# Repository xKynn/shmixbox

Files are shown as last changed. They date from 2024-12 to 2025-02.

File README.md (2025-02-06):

# shmixbox
Leverless keyboard style controller based on Open_Core0 WASD

## Attribution

Based on the Open_Core0 WASD board from the GP2040-CE project located at https://github.com/OpenStickCommunity/Hardware/tree/main/Boards/GP2040-CE%20Official%20Controllers/Open_Core0%20WASD

Copyright 2023 [TheTrain](https://github.com/TheTrainGoes)

[Licensed under CC BY 4.0](https://creativecommons.org/licenses/by/4.0/)

Changes from the original design:
  - Modified layout:
      - Wider spacing between D-pad and 8-button clusters.
      - Two Spacebar-like 2.5 - 3U keys to be accessible with thumbs.
      - A Shift-like 2-2.5U key under D-pad.
  - Modified GP2040-CE fork with the ability to address the Case LEDs and display the shmixbox layout on the OLED screen.
  - Street fighter inspired silkscreen art with case window. (Original Open_Core0 WASD art and window was removed)

Planned Changes:
  - Adjust switch spacing to comfortably fit MX-style caps in combination with Choc V2 switches.
  - Experimental Bridging of both thumb keys with one big spacebar keycap.
  - Replace 3U (?) stabilizer footprints and replace with 2.5U or find a combination that supports the bridging goal above.
  - Art cutout and acrylic plate files.

## Ordering and Assembling

With substituting the additional instructions below where applicable, the same instructions from Open_Core0 WASD can be followed from [here](https://github.com/OpenStickCommunity/Hardware/tree/main/Boards/GP2040-CE%20Official%20Controllers/Open_Core0%20WASD) (Make sure to use the hardware files from this repo)

### Additional Instructions
  - 16x Choc V1 or V2 switches (V1 recommended before the switch footprint spacing is adjusted).
  - 16x V1 or V2 keycaps.
  - 1x 2U Keycaps.
  - 2x 2-2.5U Keycaps.
  - Build or grab a prebuilt release of the firmware from [GP2040-CE-shmixbox](https://github.com/xKynn/GP2040-CE-shmixbox) instead of the Open_Core0 WASD firmware.

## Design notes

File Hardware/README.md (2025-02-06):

### JLCPCB Order Instructions

PCB:\
Base Material = FR-4\
Layers = 2\
Product Type = Industrial/Consumer electronics\
Different Design = 1\
PCB Thickness = 1.6\
PCB Color = Black\
Silkscreen = White\
Surface Finish = HASL(with lead)\
Outer Copper Weight = 1oz\
Via Covering = Tented\
Board Outline Tolerance = +/- 0.2mm (Regular)\
Confirm Production file = Yes\
Remove Order Number = Specify\
Flying Probe Test = Fully Test\
Gold Fingers = No\
Castellated Holes = No\
No advanced options\
\
Assembly:\
PCBA Type = Economic\
Assembly Side = Top Side\
Tooling holes = Added by Customer\
Confirm Parts Placement = Yes

------------------------------------------------------

Bottom Plate:\
Base Material = Aluminum\
Layers = 1\
Product Type = Industrial/Consumer electronics\
Different Design = 1\
PCB Thickness = 1.6\
PCB Color = Black\
Surface Finish = HASL(with lead)\
Outer Copper Weight = 1oz\
Via Covering = Tented\
Board Outline Tolerance = +/- 0.2mm (Regular)\
Confirm Production file = Yes\
Remove Order Number = Yes\
Flying Probe Test = Fully Test\
Gold Fingers = No\
Castellated Holes = No\
No advanced options

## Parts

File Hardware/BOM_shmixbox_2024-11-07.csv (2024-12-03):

ID | Name | Designator | Footprint | Quantity | Manufacturer Part | Manufacturer | Supplier | Supplier Part | Price | JLCPCB Part Class | Value
1 | C0402_NEW | C105,C98,C99,C100,C101,C102,C103,C104,C97,C93,C85,C33,C82,C83,C84,C80,C57,C58,C59,C60 | C0402_NEW | 20 | CL05B104KO5NNNC | SAMSUNG(三星) | LCSC | C1525 | 0.001 | Basic Part
2 | LED-SMD_4P-L2.0-W2.0-BR | U119,U112,U113,U114,U115,U116,U117,U118,U111,U96,U98,U99,U97,U100,U108,U86,U57,U58,U59,U60 | LED-SMD_4P-L2.0-W2.0-BR | 20 | SK6812-EC20 | 欧思科光电 | LCSC | C2909058 | 0.103 | Extended Part
3 | SW-TH_SK13D07VG4 | SW11,SW12 | SW-TH_SK13D07VG4 | 2 | SK13D07VG4 | SHOU HAN(首韩) | LCSC | C2681581 | 0.023 | Extended Part
4 | SW-TH_SK12D07VG4 | SW13 | SW-TH_SK12D07VG4 | 1 | SK12D07VG4 | SHOU HAN | LCSC | C393937 | 0.022 | Extended Part
5 | LED-SMD_4P-L4.0-W1.6-L | U84,U83,U82,U81,U80,U79,U78,U77,U76,U75,U109,U110,U95,U94,U93,U92,U91,U90,U89,U88 | LED-SMD_4P-L4.0-W1.6-L | 20 | SK6812SIDE-A-RVS | 欧思科光电 | LCSC | C2890037 | 0.088 | Extended Part
6 | F0805 | F1 | F0805 | 1 | MF-PSMF050X-2 | BOURNS | LCSC | C116170 | 0.034 | Extended Part
7 | R0603 | R35,R34 | R0603 | 2 | 0603WAF220JT5E | UNI-ROYAL(厚声) | LCSC | C23345 | 0.001 | Basic Part | 22Ω
8 | USB-A-TH_JTJ-USB-AF-13 | U7 | USB-A-TH_JTJ-USB-AF-13 | 1 | 905-261A1011D10100 | 精拓金 | LCSC | C42614 | 0.037
9 | SW-TH_4P-L6.0-W6.0-P4.50-LS6.5 | SW1,SW2,SW3,SW4,SW9 | SW-TH_4P-L6.0-W6.0-P4.50-LS6.5 | 5 | TS-1095-A11B3-D1 | Yuandi | LCSC | C493055 | 0.038 | Extended Part
10 | KEY-SMD_4P-L3.5-W3.0-P1.50-LS4.6 | SW8,SW7 | KEY-SMD_4P-L3.5-W3.0-P1.50-LS4.6 | 2 | TD-1182SA-2.0H-250 | DEALON(德艺隆) | LCSC | C2905178 | 0.039 | Extended Part
11 | SN74LV1T34DBVR | U87 | SOT-23-5_L2.9-W1.6-P0.95-LS2.8-BR | 1 | SN74LV1T34DBVR | TI(德州仪器) | LCSC | C100024 | 0.189 | Extended Part
12 | 10kΩ | R33,R29,R23 | R0402 | 3 | 0402WGF1002TCE | UNI-ROYAL(厚声) | LCSC | C25744 | 0.001 | Basic Part
13 | 100nF | C81,C18 | C0402 | 2 | CL05B104KO5NNNC | SAMSUNG(三星) | LCSC | C1525 | 0.001 | Basic Part
14 | AMS1117-3.3 | U85 | SOT-223-3_L6.5-W3.4-P2.30-LS7.0-BR | 1 | AMS1117-3.3 | AMS | LCSC | C6186 | 0.136 | Basic Part
15 | 0Ω | R30 | R0603 | 1 | 0603WAF0000T5E | UNI-ROYAL(厚声) | LCSC | C21189 | 0.001 | Basic Part
16 | 5.1kΩ | R31,R32 | R0402 | 2 | 0402WGF5101TCE | UNI-ROYAL(厚声) | LCSC | C25905 | 0.001 | Basic Part
17 | SMF05CT1G | D2 | SOT-363_L2.0-W1.3-P0.65-LS2.1-TL | 1 | SMF05CT1G | onsemi(安森美) | LCSC | C15879 | 0.146 | Basic Part
18 | 10uF | C78,C79 | C1206 | 2 | CL31A106KBHNNNE | SAMSUNG(三星) | LCSC | C13585 | 0.032 | Basic Part
19 | TYPE-C 16PIN 2MD(073) | USB2 | USB-C-SMD_TYPE-C-6PIN-2MD-073 | 1 | TYPE-C 16PIN 2MD(073) | SHOU HAN(首韩) | LCSC | C2765186 | 0.054 | Extended Part
20 | 33pF | C63,C64 | C0402 | 2 | 0402CG330J500NT | FH(风华) | LCSC | C1562 | 0.001 | Basic Part
21 | 1uF | C65,C66 | C0402 | 2 | CL05A105KA5NQNC | SAMSUNG(三星) | LCSC | C52923 | 0.003 | Basic Part
22 | 100nF | C67,C68,C69,C70,C71,C72,C73,C74,C75,C76,C77 | C0402_NEW | 11 | CL05B104KO5NNNC | SAMSUNG(三星) | LCSC | C1525 | 0.001 | Basic Part
23 | 1kΩ | R1,R26,R24 | R0402 | 3 | 0402WGF1001TCE | UNI-ROYAL(厚声) | LCSC | C11702 | 0.001 | Basic Part
24 | 22Ω | R28,R27 | R0402 | 2 | 0402WGF220JTCE | UNI-ROYAL(厚声) | LCSC | C25092 | 0.001 | Basic Part
25 | RP2040 | U61 | LQFN-56_L7.0-W7.0-P0.4-EP | 1 | RP2040 | Raspberry Pi(树莓派) | LCSC | C2040 | 1.056 | Extended Part
26 | W25Q128JVSIQTR | U6 | SOIC-8_L5.3-W5.3-P1.27-LS8.0-BL | 1 | W25Q128JVSIQ | WINBOND(华邦) | LCSC | C97521 | 0.527 | Basic Part
27 | 12MHz | X2 | OSC-SMD_4P-L3.2-W2.5-BL | 1 | X322512MSB4SI | YXC | LCSC | C9002 | 0.063 | Basic Part
28 | R0603 | R3,R2 | R0603 | 2 | 0603WAF4701T5E | UNI-ROYAL(厚声) | LCSC | C23162 | 0.001 | Basic Part

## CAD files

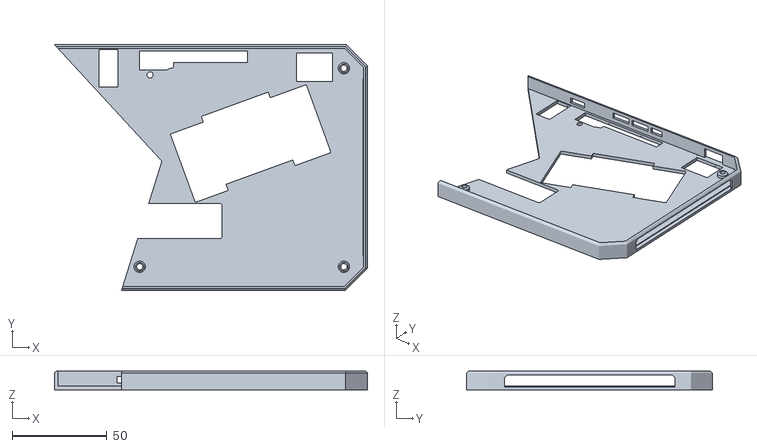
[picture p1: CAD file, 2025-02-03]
3D Print Files/Split/shmixbox_main_frame_top_split_right.stl
165.6 x 130.0 x 10.00

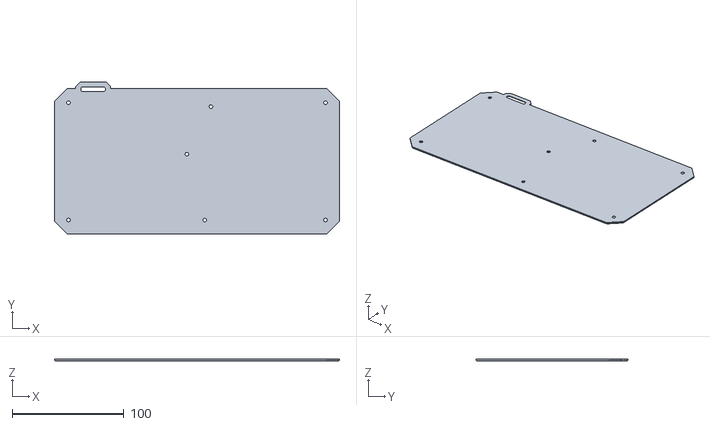
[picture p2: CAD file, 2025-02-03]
3D Print Files/shmixbox_main_frame_bottom.stl
255.0 x 136.0 x 2.10

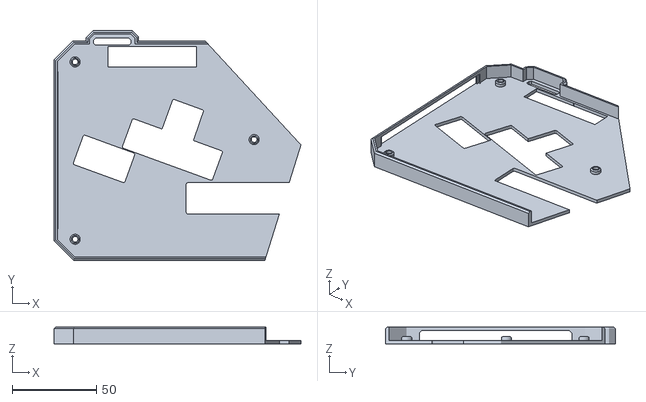
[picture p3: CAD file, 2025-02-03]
3D Print Files/Split/shmixbox_main_frame_top_split_left.stl
146.2 x 136.0 x 10.00

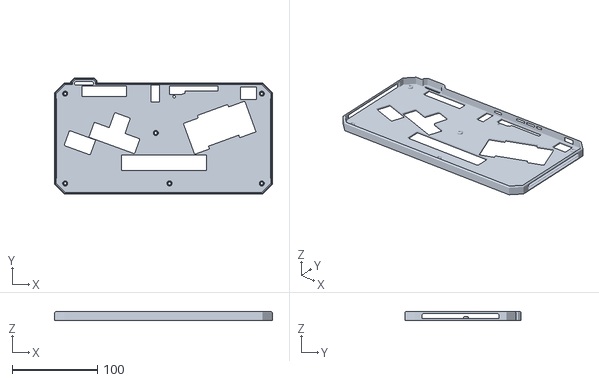
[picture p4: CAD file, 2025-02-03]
3D Print Files/shmixbox_main_frame_top.stl
255.0 x 136.0 x 10.00

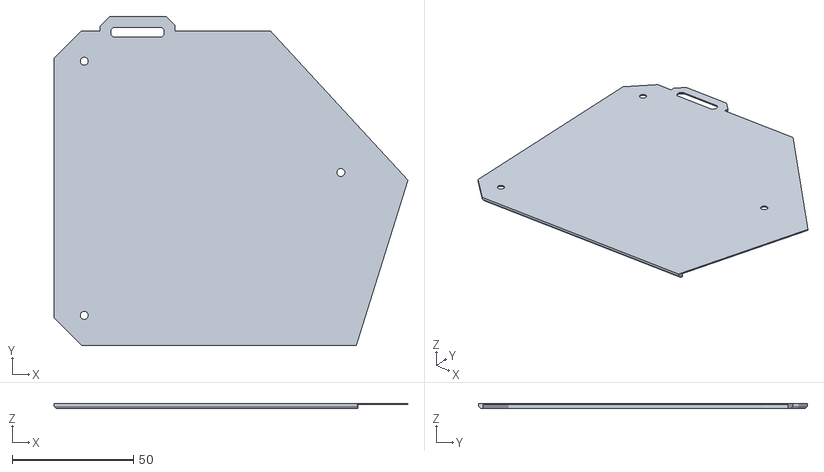
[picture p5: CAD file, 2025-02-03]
3D Print Files/Split/shmixbox_main_frame_bottom_split_left.stl
146.2 x 136.0 x 2.10

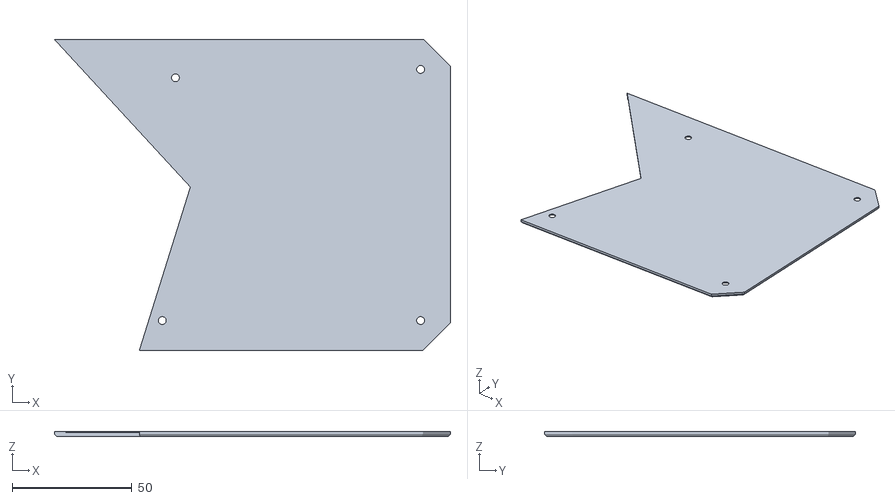
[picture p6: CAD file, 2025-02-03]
3D Print Files/Split/shmixbox_main_frame_bottom_split_right.stl
165.6 x 130.0 x 2.10

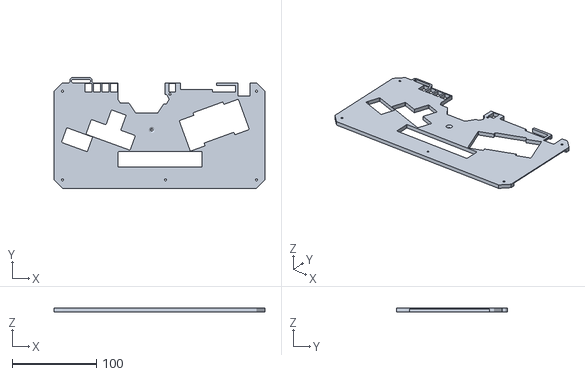
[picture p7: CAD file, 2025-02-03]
3D Print Files/shmixbox_top_insert_no_cutout.stl
250.0 x 131.0 x 4.50

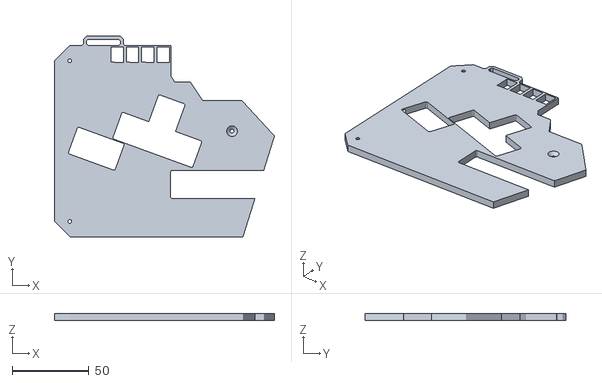
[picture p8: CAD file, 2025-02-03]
3D Print Files/Split/shmixbox_top_insert_split_left_no_cutout.stl
143.7 x 131.0 x 4.50

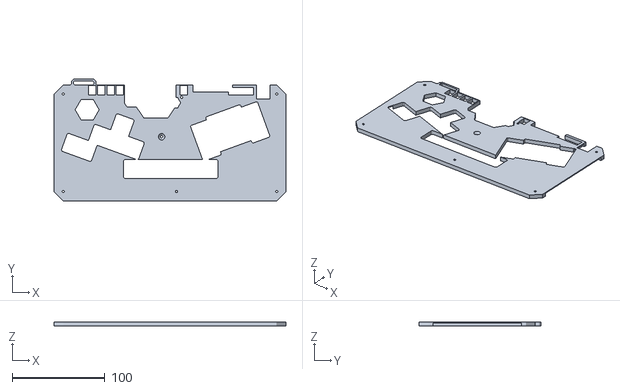
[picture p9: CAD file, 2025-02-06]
3D Print Files/Top Insert Extra Clearance Ver/shmixbox_extra_clearance_top_insert.stl
250.0 x 131.0 x 4.50

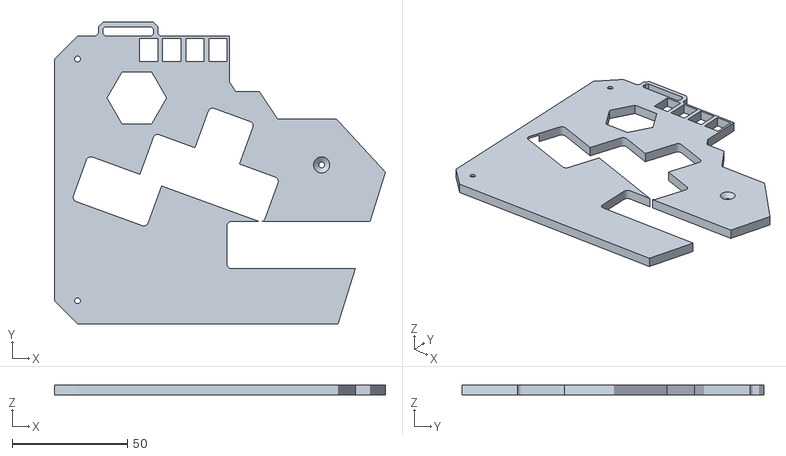
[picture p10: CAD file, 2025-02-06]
3D Print Files/Top Insert Extra Clearance Ver/Split/shmixbox_extra_clearance_top_insert_left_split.stl
143.7 x 131.0 x 4.50

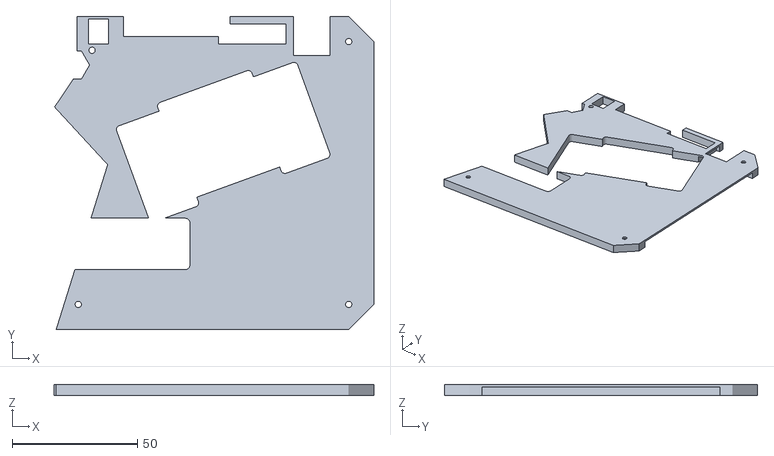
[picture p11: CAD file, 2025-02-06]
3D Print Files/Top Insert Extra Clearance Ver/Split/shmixbox_extra_clearance_top_insert_right_split.stl
127.6 x 125.0 x 4.50

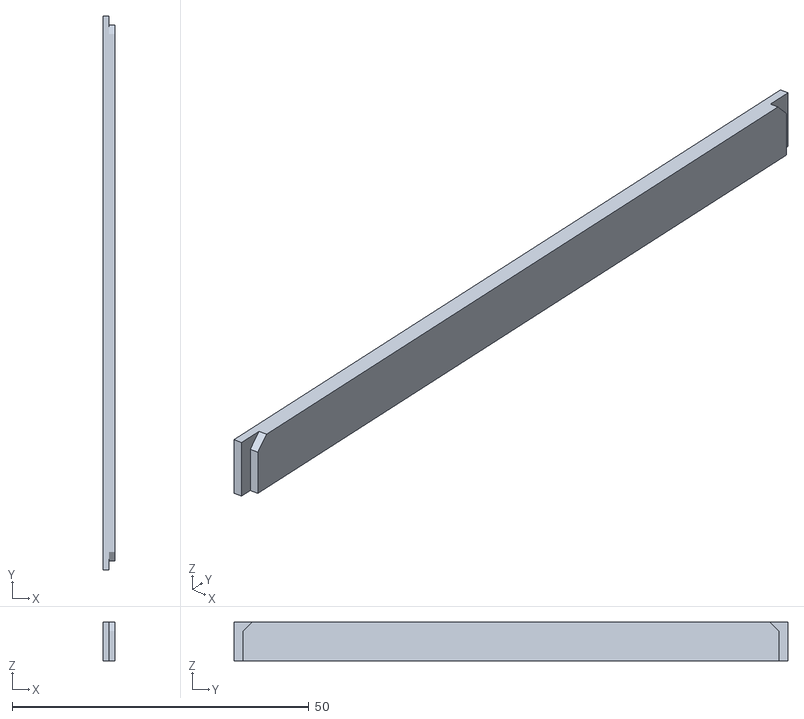
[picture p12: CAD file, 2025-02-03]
3D Print Files/LED_Diffuser (Resin).stl
2.00 x 93.3 x 6.50

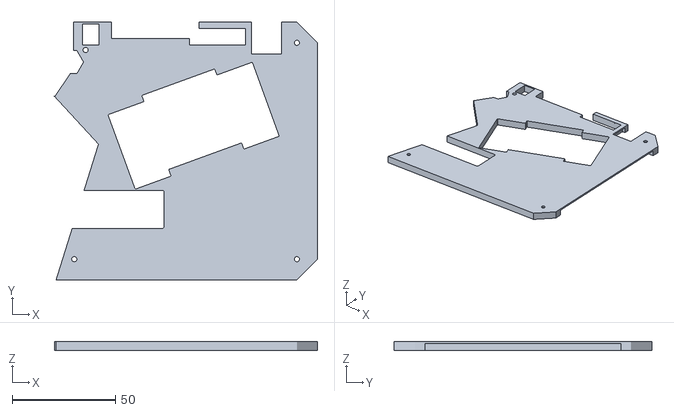
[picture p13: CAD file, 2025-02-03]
3D Print Files/Split/shmixbox_top_insert_split_right_cutout_VER.stl
127.6 x 125.0 x 4.50

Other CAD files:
3D Print Files/shmixbox_top_insert_cutout_VER.stl
3D Print Files/Split/shmixbox_top_insert_split_left_cutout_VER.stl

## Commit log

2024-12-03 Add Hardware and Source files
    [BOM_shmixbox_2024-11-07.csv, PickAndPlace_PCB_shmixbox_2024-11-07.csv]
2025-02-03 Add 3D Print Files and update Readme
    [LED_Diffuser (Resin).stl, shmixbox_main_frame_bottom.stl, shmixbox_main_frame_bottom_split_left.stl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]
2025-02-06 Add extra clearance / wider MX keycaps top insert files
    [shmixbox_extra_clearance_top_insert.stl, shmixbox_extra_clearance_top_insert_left_split.stl, shmixbox_extra_clearance_top_insert_right_split.stl]
